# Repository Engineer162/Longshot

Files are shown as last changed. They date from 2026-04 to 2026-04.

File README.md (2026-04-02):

# Longshot

## What This Project Is

Longshot is an open hardware and firmware project for designing and building a custom RF communication module.

This repository contains:
- EDA design files for the schematic and PCB layout
- Firmware sources for bring-up and control of the radio system
- Supporting documentation and licenses for development and release

Current version sends/recieves at 868MHz, but this can be changed in firmware, and by changing matching and lowpass filters in the schematic.

Why did i feel the need to create such a module from scratch? Because i simply wasnt satisfied by the speed & range that other modules like LoRa had, so i created my own.

## RF Main Components

| Function | IC / Module |
| --- | --- |
| Transceiver IC | SI4463 |
| PA / LNA | SKY66423-11 |

---

<sub>Note: I tried to use copilot AI to generate this repo structure as i have not tried that before. Safe to say i wont be attempting that in any future repo's. </sub>

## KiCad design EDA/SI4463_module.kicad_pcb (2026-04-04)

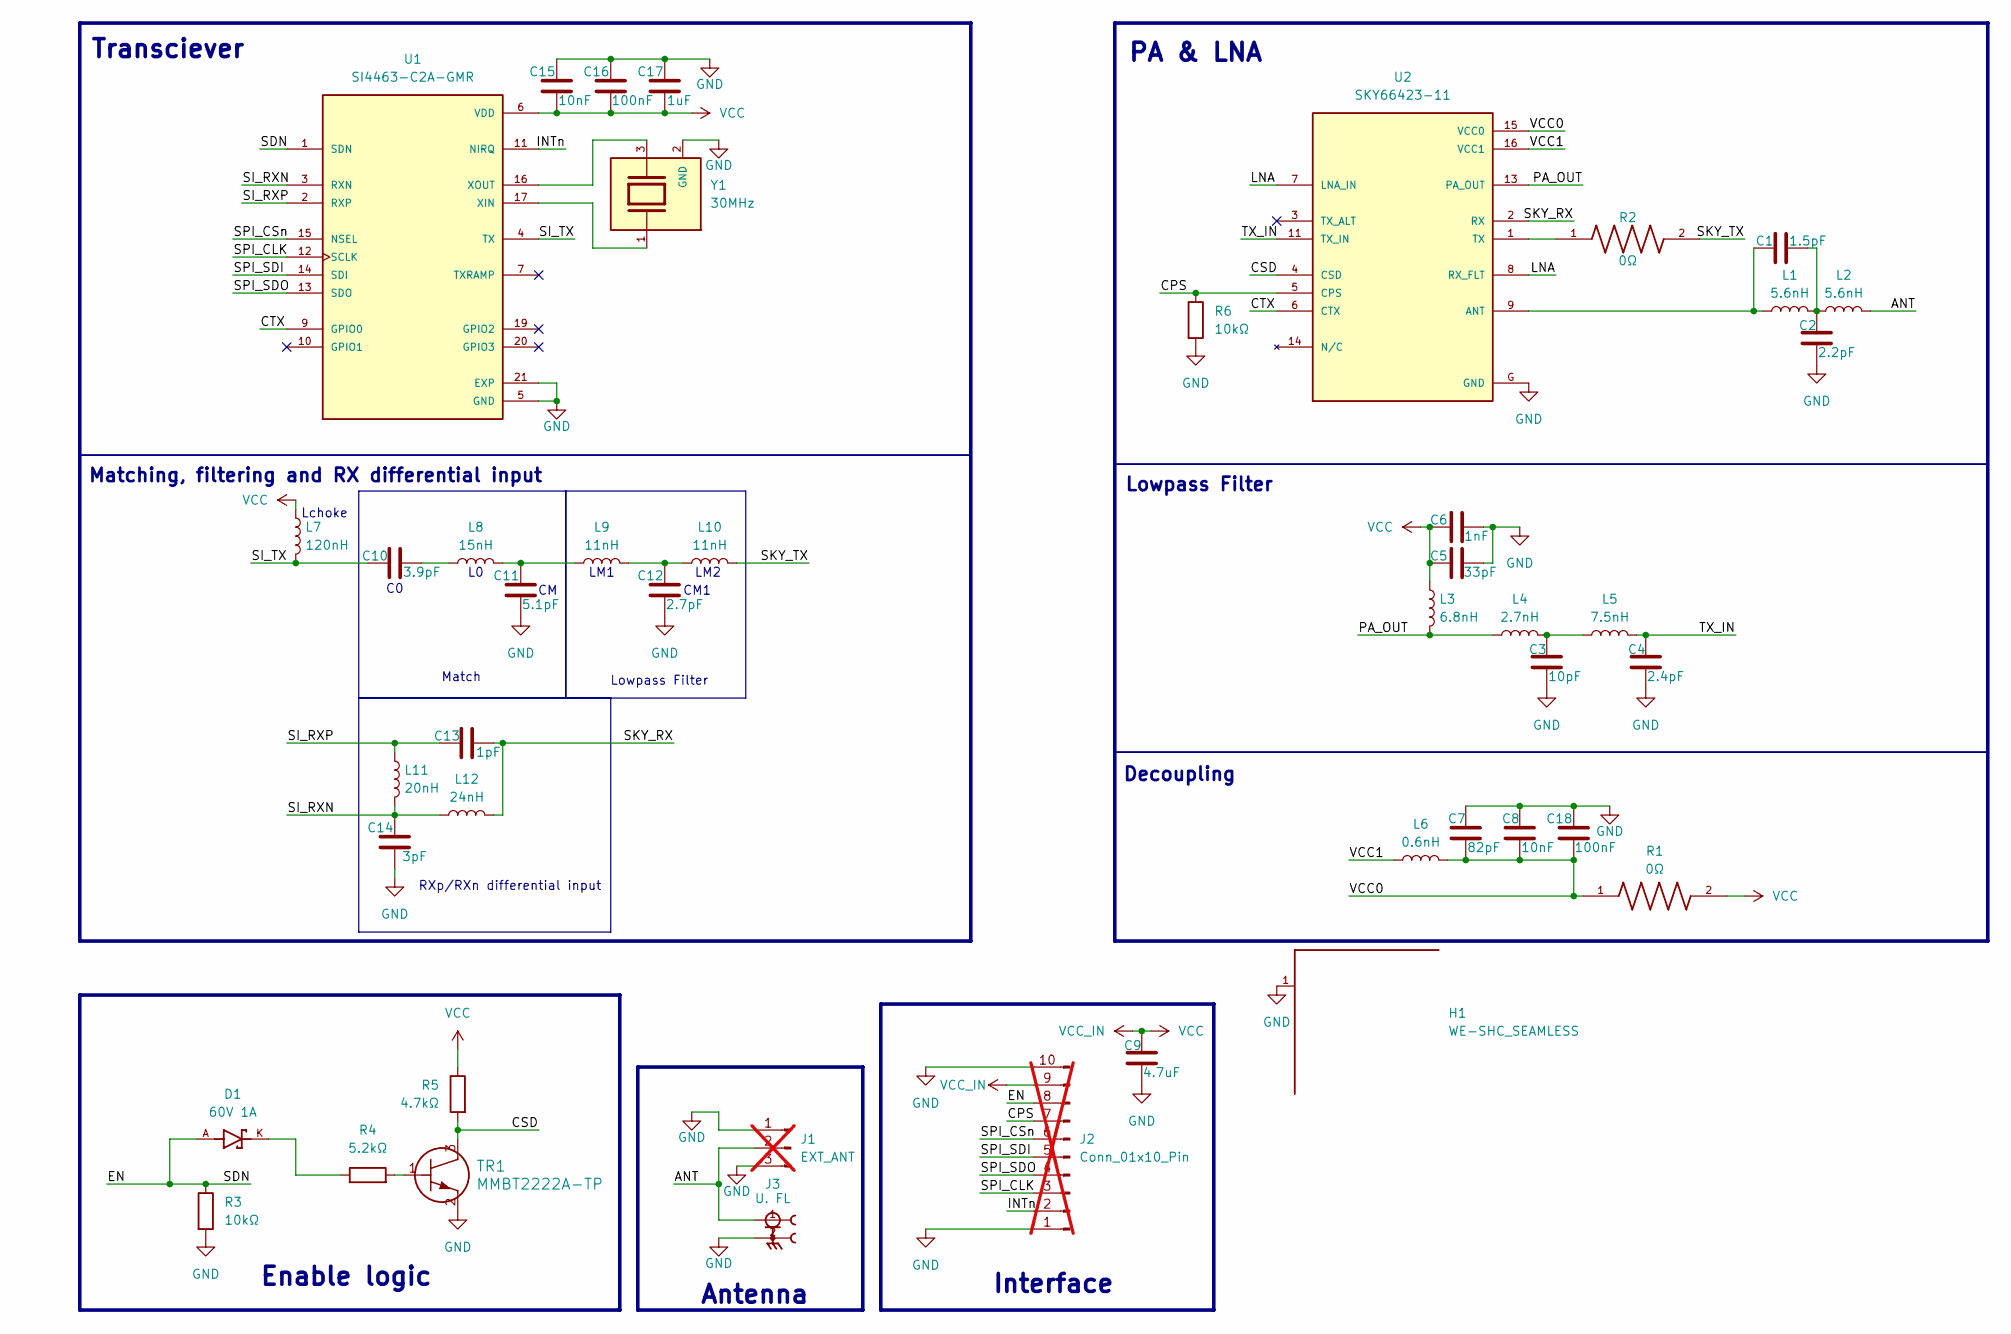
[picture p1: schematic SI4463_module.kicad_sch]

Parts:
C1: 1.5pF; C_0402_1005Metric
C2: 2.2pF; C_0402_1005Metric
C3: 10pF; C_0402_1005Metric
C4: 2.4pF; C_0402_1005Metric
C5: 33pF; C_0402_1005Metric
C6: 1nF; C_0402_1005Metric
C7: 82pF; C_0402_1005Metric
C8, C15: 10nF; C_0603_1608Metric
C9: 4.7uF; C_0603_1608Metric
C10: 3.9pF; C_0402_1005Metric
C11: 5.1pF; C_0402_1005Metric
C12: 2.7pF; C_0402_1005Metric
C13: 1pF; C_0402_1005Metric
C14: 3pF; C_0402_1005Metric
C16, C18: 100nF; C_1206_3216Metric
C17: 1uF; C_0603_1608Metric
D1: 60V 1A; DIO_MSS1P6-M3_89A; PARTREV 03-Aug-2020; DigiKey_Part_Number MSS1P6-M3/89AGICT-ND
H1: WE-SHC_SEAMLESS; WE-SHC_SEAMLESS_3670310; DigiKey_Part_Number 732-3670310-ND
J1: EXT_ANT; PinHeader_1x03_P2.00mm_Vertical; not fitted
J2: Conn_01x10_Pin; PinHeader_1x10_P2.00mm_Vertical; not fitted
J3: U. FL; LINX_CONUFL001-SMD-T; DigiKey_Part_Number CONUFL001-SMD-TCT-ND
L1, L2: 5.6nH; L_0402_1005Metric
L3: 6.8nH; L_0402_1005Metric
L4: 2.7nH; L_0402_1005Metric
L5: 7.5nH; L_0402_1005Metric
L6: 0.6nH; L_0201_0603Metric
L7: 120nH; L_0603_1608Metric
L8: 15nH; L_0402_1005Metric
L9, L10: 11nH; L_0201_0603Metric
L11: 20nH; L_0402_1005Metric
L12: 24nH; L_0805_2012Metric
R1, R2: 0Ω; RES_ERJ-2GE0R00X; PARTREV 3/1/2020; DigiKey_Part_Number P0.0JCT-ND
R3, R6: 10kΩ; R_0402_1005Metric
R4: 5.2kΩ; R_0805_2012Metric
R5: 4.7kΩ; R_0402_1005Metric
TR1: MMBT2222A-TP; MTR_MMBT2222A-TP_MCE
U1: SI4463-C2A-GMR; QFN50P400X400X90-21N; PARTREV 1.0; DigiKey_Part_Number 336-4346-1-ND
U2: SKY66423-11; XCVR_SKY66423-11; PARTREV June 9, 2023; DigiKey_Part_Number 863-2030-1-ND
Y1: 30MHz; XTAL_ABM8-30.000MHz-10-B1U-T; PARTREV 44041; DigiKey_Part_Number 535-14988-1-ND

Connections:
/ANT: J1.2, J3.1, L2.2
/CPS: J2.7, R6.1, U2.5 (CPS)
/CSD: R5.2, TR1.3, U2.4 (CSD)
/CTX: U1.9 (GPIO0), U2.6 (CTX)
/EN: D1.A, J2.8, R3.1, U1.1 (SDN)
/INTn: J2.2, U1.11 (NIRQ)
/LNA: U2.7 (LNA_IN), U2.8 (RX_FLT)
/PA_OUT: L3.2, L4.1, U2.13 (PA_OUT)
/SI_RXN: C14.2, L11.2, L12.1, U1.3 (RXN)
/SI_RXP: C13.1, L11.1, U1.2 (RXP)
/SI_TX: C10.1, L7.2, U1.4 (TX)
/SKY_RX: C13.2, L12.2, U2.2 (RX)
/SKY_TX: L10.2, R2.2
/SPI_CLK: J2.3, U1.12 (SCLK)
/SPI_CSn: J2.6, U1.15 (NSEL)
/SPI_SDI: J2.5, U1.14 (SDI)
/SPI_SDO: J2.4, U1.13 (SDO)
/TX_IN: C4.2, L5.2, U2.11 (TX_IN)
/VCC0: C7.1, C8.1, C18.1, L6.2, R1.1, U2.15 (VCC0)
/VCC1: L6.1, U2.16 (VCC1)
GND: C2.1, C3.1, C4.1, C5.2, C6.2, C7.2, C8.2, C9.1, C11.1, C12.1, C14.1, C15.2, C16.2, C17.2, C18.2, H1.1, H1.2, H1.3, H1.4, J1.1, J1.3, J2.1, J2.10, J3.2, J3.3, R3.2, R6.2, TR1.2, U1.5 (GND), U1.18 (GND), U1.21 (EXP), U2.G (GND), Y1.2 (GND), Y1.4 (GND)
unnamed: C1.2, C2.2, L1.2, L2.1
unnamed: C3.2, L4.2, L5.1
unnamed: C10.2, L8.1
unnamed: C11.2, L8.2, L9.1
unnamed: C12.2, L9.2, L10.1
unnamed: D1.K, R4.1
unnamed: R4.2, TR1.1
unnamed: U1.17 (XIN), Y1.1
unnamed: U1.16 (XOUT), Y1.3
unnamed: C1.1, L1.1, U2.9 (ANT)
unnamed: R2.1, U2.1 (TX)
VCC: C5.1, C6.1, C9.2, C15.1, C16.1, C17.1, J2.9, L3.1, L7.1, R1.2, R5.1, U1.6 (VDD), U1.8 (VDD)

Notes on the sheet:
PA & LNA
RXp/RXn differential input
CM1
Enable logic
Lowpass Filter
Lchoke
Transciever
LM1
LM2
Decoupling
Antenna
Matching, filtering and RX differential input
Match
Interface

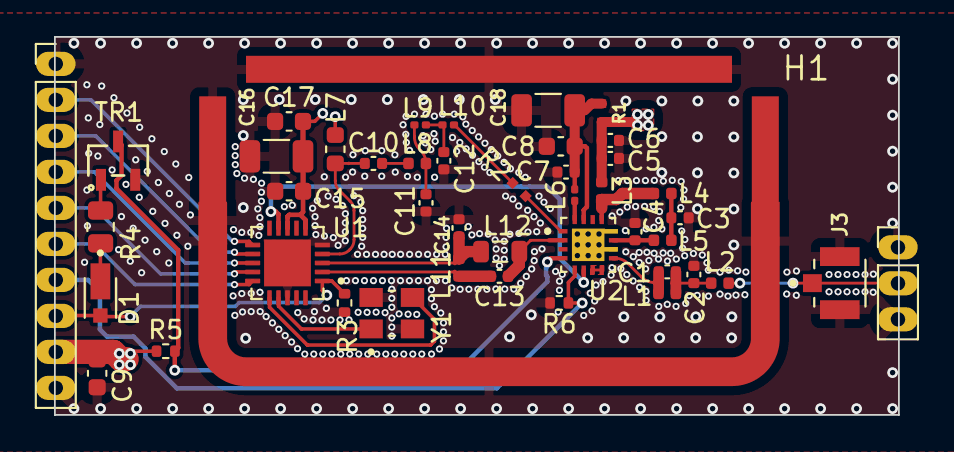
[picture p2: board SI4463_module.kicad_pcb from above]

Board: 4 copper layers, 46.9 x 21.0 mm, 45 parts (0 on the bottom side), 33 nets.

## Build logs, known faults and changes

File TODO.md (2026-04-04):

- [x] Make schematic
- [x] Assign MPN's
- [x] Assign footprints
- [x] Make base PCB
- [x] Place components
- [x] Trace PCB
- [x] Impedance match RF traces
- [x] Add fill zones
- [ ] Write firmware
- [ ] Test
- [ ] Release stable V1

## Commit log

2026-04-02 Pushed schematic progress
    [SI4463_module.kicad_pcb, SI4463_module.kicad_sch]
2026-04-03 Added edge headers, and assigned MPN's and footprints.
    [SI4463_module.kicad_sch]
2026-04-03 Made PCB, placed components, routed almost all of them (missing power traces). added EMI shield.
    [SI4463_module.kicad_pcb, SI4463_module.kicad_sch]
2026-04-04 Finished PCB
    [SI4463_module.kicad_pcb]
2026-04-04 Forgot to add stitching on RX differential input section.
    [SI4463_module.kicad_pcb]
2026-04-04 added 2 missing traces
    [SI4463_module.kicad_pcb]
